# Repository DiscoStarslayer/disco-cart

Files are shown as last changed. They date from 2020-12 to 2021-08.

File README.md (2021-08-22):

# V.Smile Disco-Cart
Custom developer cartridge that easily enables the following
- Ability to dump retail cartridges over Serial or to an SD card
- Ability to flash roms over serial or an SD card to built in flash memory
- Booting cartridge on real V.Smile hardware
- Use Teensy to fuzz data + address bus while system is online (WIP)
- "Stealth" switch to disable sense pinout to allow console to boot as if Cartridge was not inserted

## Contents

- [Cartridge](#cartridge)
- [Usage](#usage)
- [Examples](#examples)
    + [Read retail cartridge to local file over serial](#read-retail-cartridge-to-local-file-over-serial)
    + [Dump retail cartridge to SD card](#dump-retail-cartridge-to-sd-card)
    + [Flash local rom to flashcart](#flash-local-rom-to-flashcart)
- [Args](#args)
    + [`port`](#-port-)
    + [`out`](#-out-)
    + [`limit`](#-limit-)
    + [`bank`](#-bank-)
    + [`mode`](#-mode-)
    + [`name`](#-name-)
    + [`length`](#-length-)
- [Contributing](#contributing)

## Cartridge

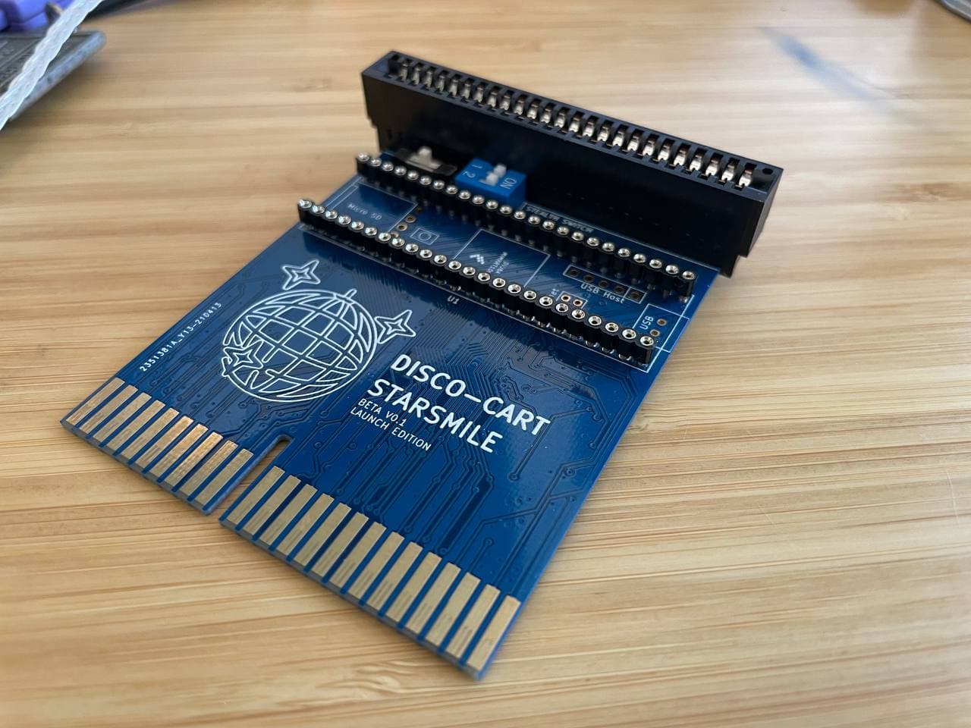
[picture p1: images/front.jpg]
Disco-Cart Front

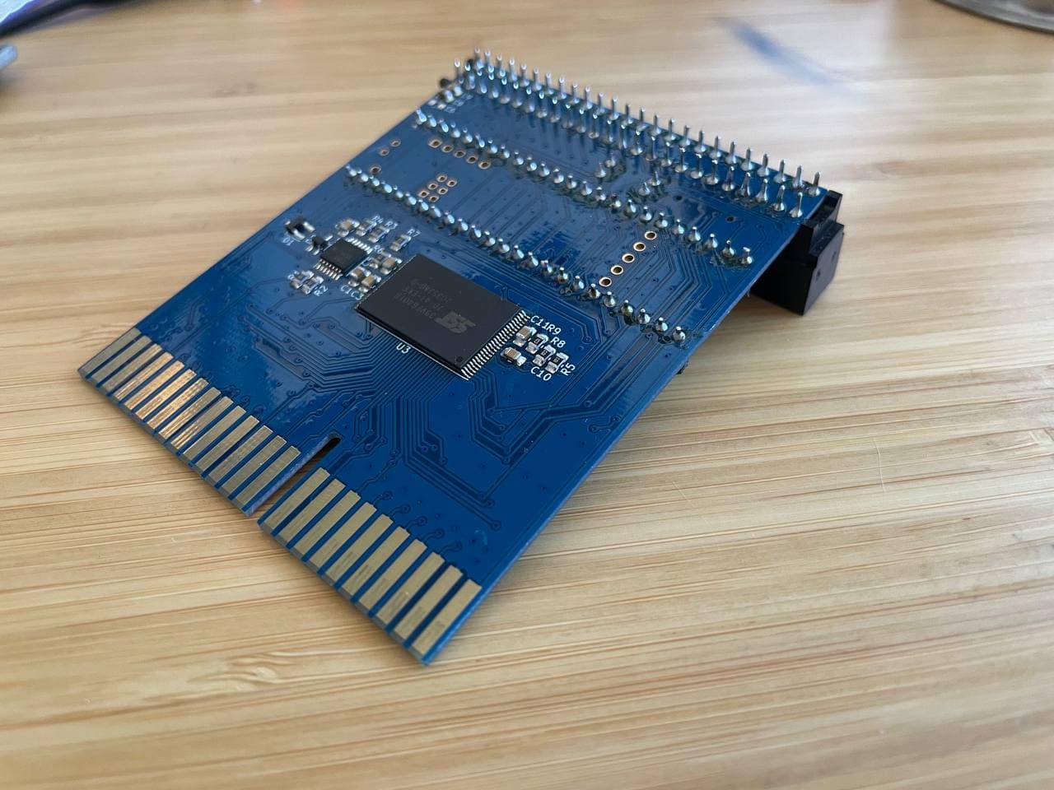
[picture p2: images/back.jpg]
Disco-Cart Back


## Usage

1. Install [PlatformIO](https://platformio.org/) onto your local system.
2. Install latest LTS for [NodeJS](https://nodejs.org/en/) onto your local system.
3. Install supporting packages for serial management script: 
```shell
cd ./manager
yarn
```
4. Use PlatformIO to pull in required packages, build, and then deploy firmware onto your Teensy (optionally, flash [`firmware.hex`](https://github.com/DiscoStarslayer/vsmile-dumper/releases/download/v0.1/firmware.hex))
5. Socket Teensy into Disco-Cart, ensure USB port on teensy lines up with the USB silkscreen on the board
6. Move mode select switch to the desired position
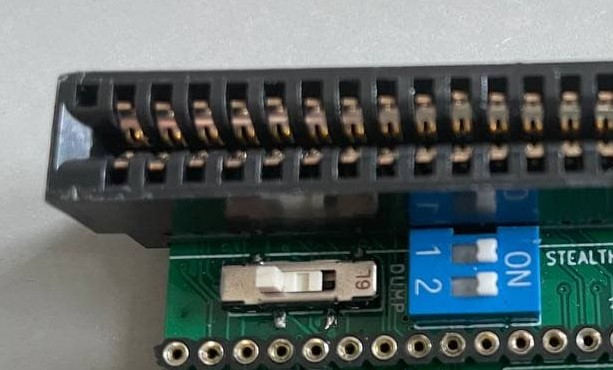
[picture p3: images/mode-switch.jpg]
Mode Select Switch

- `Left`: Cart mode, to insert into a V-Smile and boot a flashed rom
- `Middle`: Flash mode, select this mode to read/write to the internal flash on the Disco-Cart
- `Right`: Dump mode, select this mode to read/write from an inserted retail cartridge
7. Use manager scripts to perform your desired action

## Examples

### Read retail cartridge to local file over serial

```shell
# Switch: Dump mode
node .\index.js --port=COM3 --out=./thomas.bin --limit=3FFFFF --bank=LOW
```

### Dump retail cartridge to SD card

```shell
# Switch: Dump mode
node .\index.js --port=COM3 --mode=sddump --name=thomas.bin --length=3FFFFF
```

### Flash local rom to flashcart

```shell
# Switch: Write mode
node .\index.js --port=COM3 --mode=write --rom=./thomas.bin
```

### Inserting into a V.Smile
Ensure mode select switch is in Cart mode. Teensy can remain inserted in cartridge while in this mode. If you wish to write a new flash, you can do so while the cartridge is inserted by first switching mode to Write mode and running the write action from the manager

## Args

### `port`

Determines the serial port to connect to, defaults to `COM3` for Windows or `/dev/ttyACM0` for Linux.

### `out`

Relative file path to write the rom dump to, defaults to `./dump.bin`

### `limit`

Max address to dump to in hex. Banked cartridges generally have a 4MB and 2MB flash, so they need a limit of `1FFFFF` and `FFFFF` respectively. A single 8MB flash should accept `3FFFFF`.

### `bank`

If cartridge is banked, select which bank to dump. Defaults to `LOW`, non-banked cartridges should be set to `LOW`.

### `mode`

Which mode to operate the teensy in. Accepts `dump`, `write` and `sddump`.

### `name`

When writing to SD card, the file name to write to

### `length`

When writing to SD card, the size of the file to be written, in hex.

## Contributing

Project is fully open source under GPL3, including hardware design.
- `cartridge`: Hardware design as a KiCad Project
- `manager`: JS Script to aid with interfacing the Teensy over serial
- `src`: C++ Platform IO source for Teensy 4.1

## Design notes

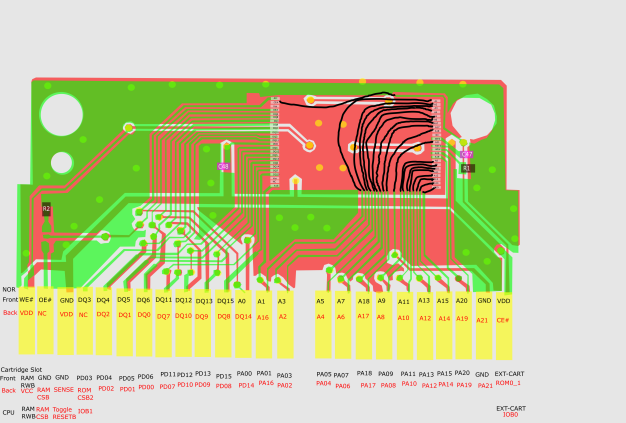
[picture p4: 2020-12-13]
docs/vsmile-pinout.png

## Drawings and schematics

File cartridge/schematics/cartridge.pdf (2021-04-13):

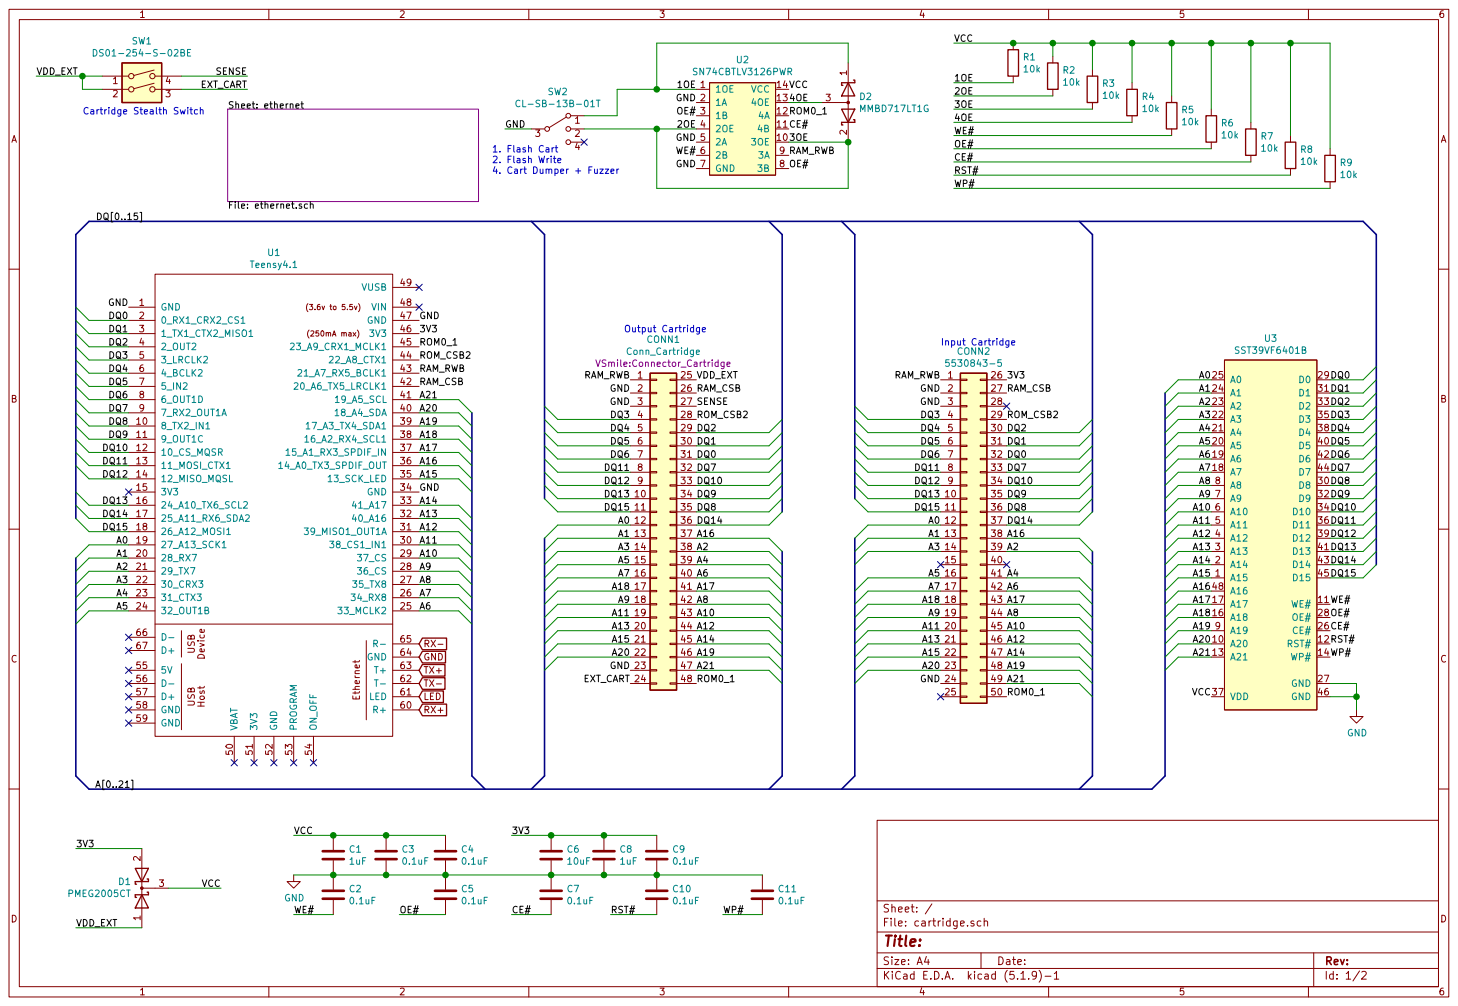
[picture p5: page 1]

WP# RST# CE# OE# WE# VCC

1. Flash Cart 2. Flash Write
4. Cart Dumper + Fuzzer

File: cartridge.sch Sheet: /
Id: 1/2 Title:

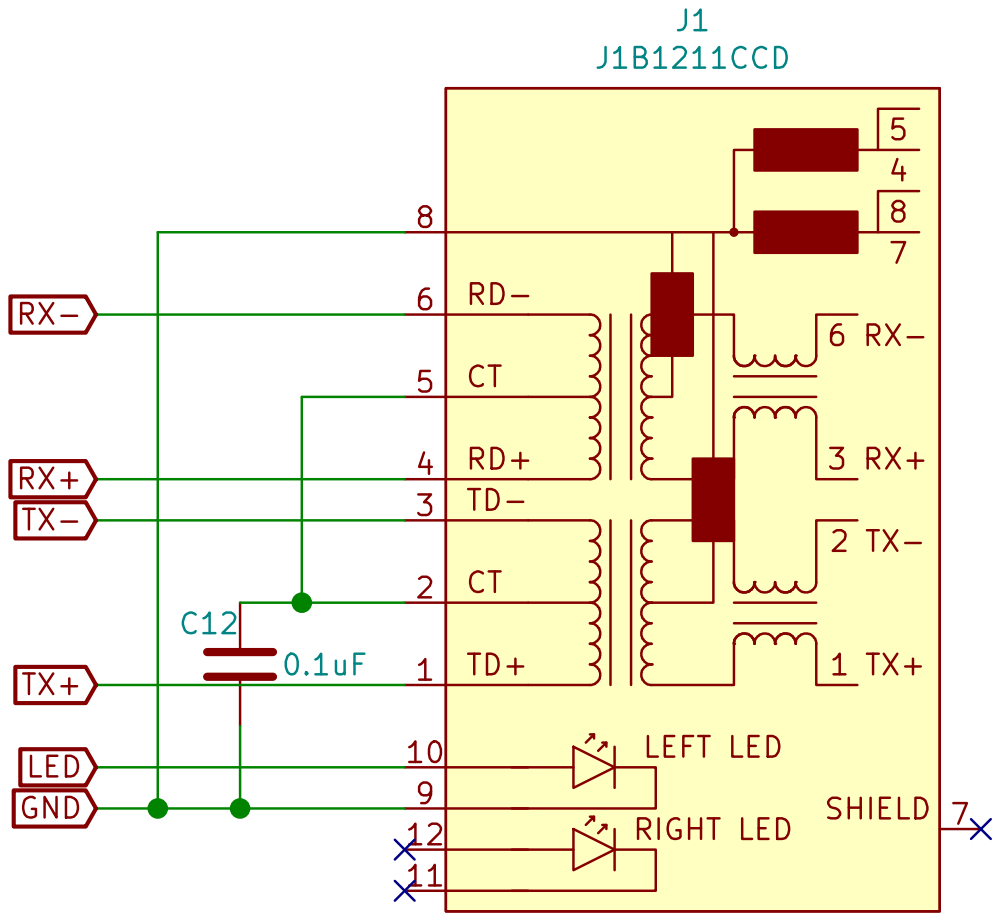
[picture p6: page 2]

0.1uF TX+ RX+ RX- LED GND

Id: 2/2 Title: File: ethernet.sch Sheet: /ethernet/

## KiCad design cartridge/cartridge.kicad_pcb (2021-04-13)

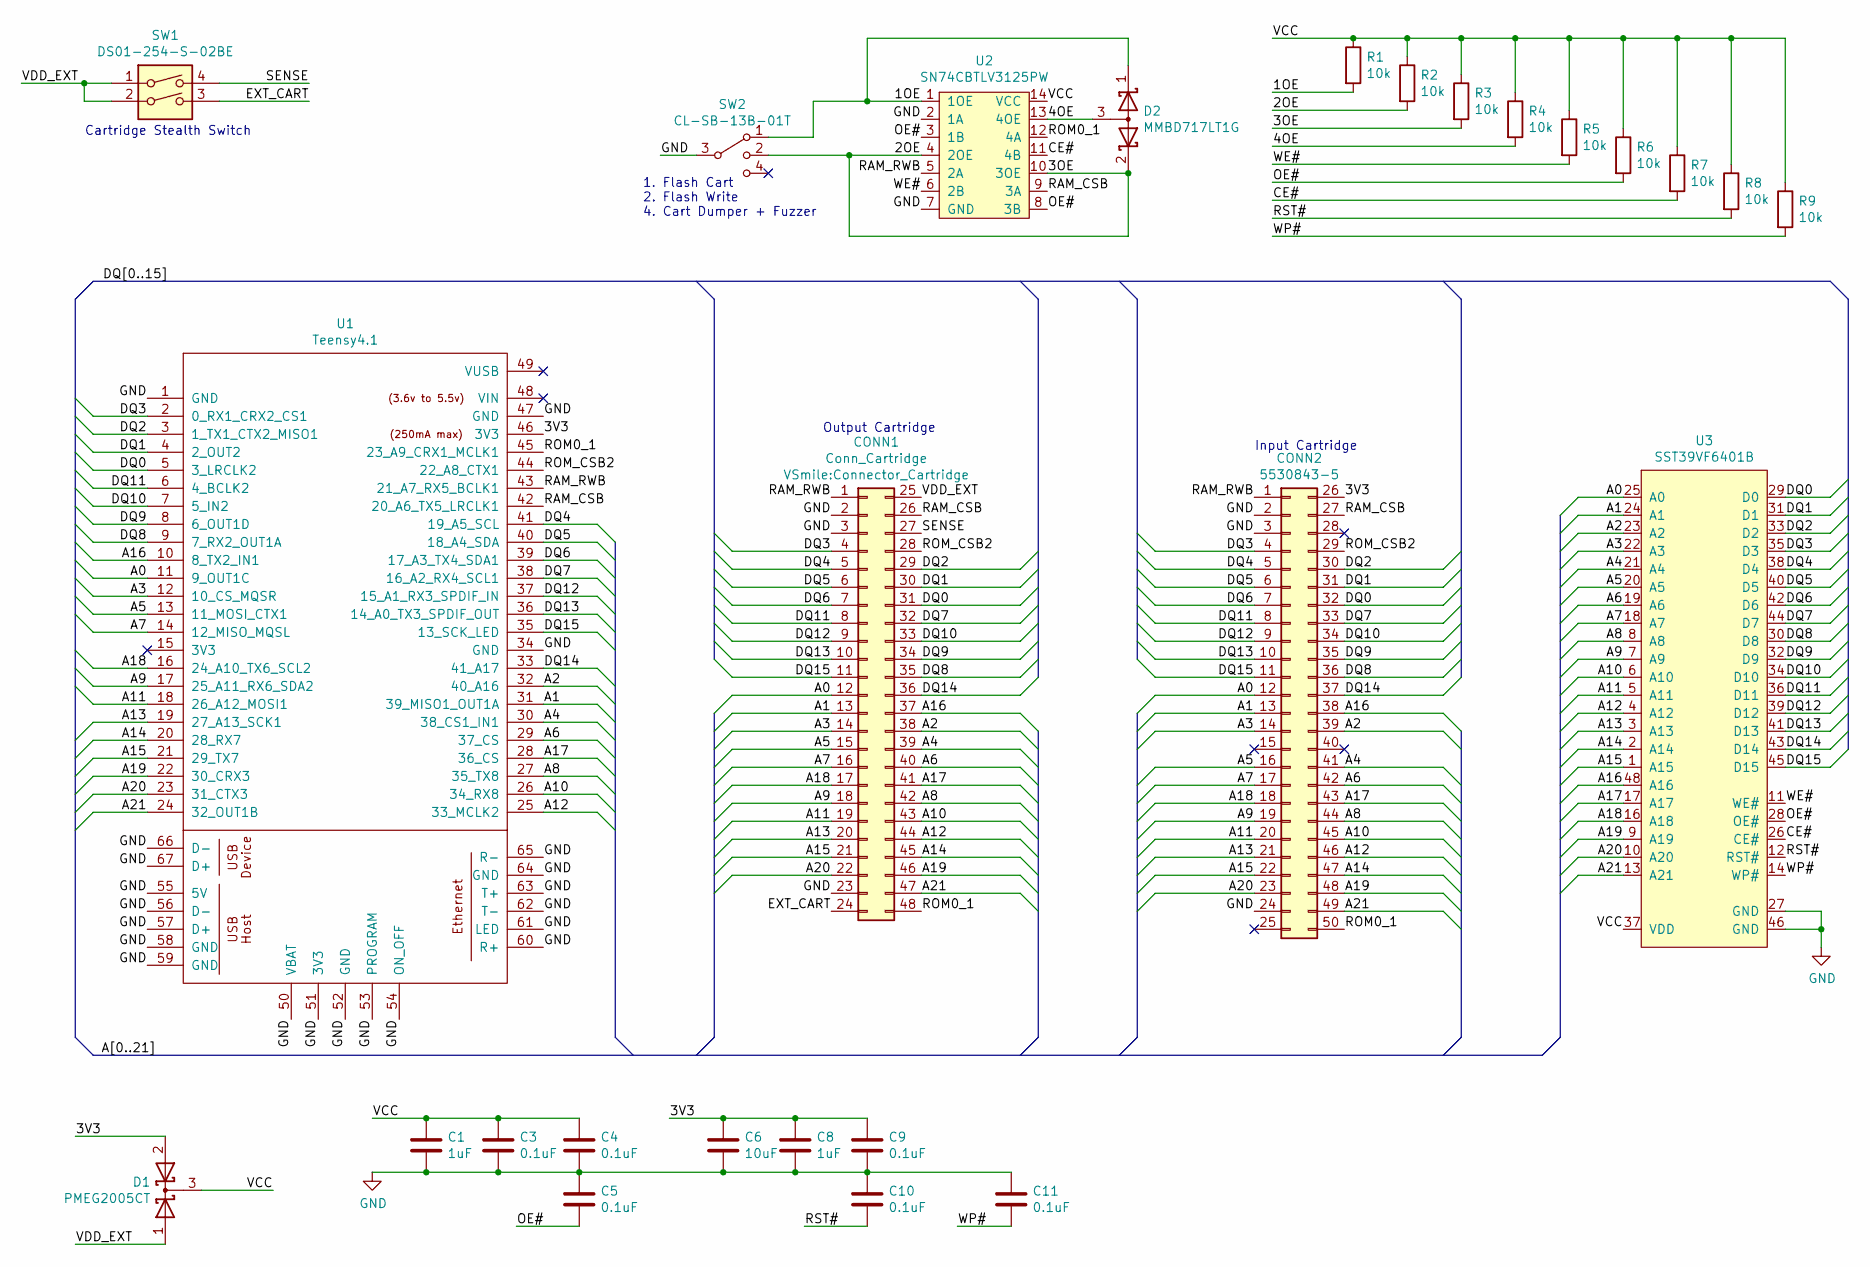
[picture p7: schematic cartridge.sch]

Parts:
C1, C8: 1uF; C_0805_2012Metric_Pad1.18x1.45mm_HandSolder
C3, C4, C5, C9, C10, C11: 0.1uF; C_0805_2012Metric_Pad1.18x1.45mm_HandSolder
C6: 10uF; C_0805_2012Metric_Pad1.18x1.45mm_HandSolder
CONN1: Conn_Cartridge; Connector_Cartridge
CONN2: 5530843-5
D1: PMEG2005CT; SOT-23_Handsoldering
D2: MMBD717LT1G‎; SOT-323_SC-70_Handsoldering
R1, R2, R3, R4, R5, R6, R7, R8, R9: 10k; R_0805_2012Metric_Pad1.20x1.40mm_HandSolder
SW1: DS01-254-S-02BE
SW2: CL-SB-13B-01T‎; CL-SB-13B-01T
U1: Teensy4.1; Teensy41
U2: SN74CBTLV3125PW; TSSOP-14_4.4x5mm_P0.65mm
U3: SST39VF6401B; TSOP-I-48_18.4x12mm_P0.5mm

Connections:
/1OE: D2.1 (K), R1.2, SW2.1, U2.1 (1OE)
/2OE: D2.2 (K), R2.2, R3.2, SW2.2, U2.4 (2OE), U2.10 (3OE)
/3V3: C6.1, C8.1, C9.1, CONN2.26, D1.2 (A), U1.46 (3V3)
/4OE: D2.3 (A), R4.2, U2.13 (4OE)
/A0: CONN1.12, CONN2.12, U1.11 (9_OUT1C), U3.25 (A0)
/A1: CONN1.13, CONN2.13, U1.31 (39_MISO1_OUT1A), U3.24 (A1)
/A2: CONN1.38, CONN2.39, U1.32 (40_A16), U3.23 (A2)
/A3: CONN1.14, CONN2.14, U1.12 (10_CS_MQSR), U3.22 (A3)
/A4: CONN1.39, CONN2.41, U1.30 (38_CS1_IN1), U3.21 (A4)
/A5: CONN1.15, CONN2.16, U1.13 (11_MOSI_CTX1), U3.20 (A5)
/A6: CONN1.40, CONN2.42, U1.29 (37_CS), U3.19 (A6)
/A7: CONN1.16, CONN2.17, U1.14 (12_MISO_MQSL), U3.18 (A7)
/A8: CONN1.42, CONN2.44, U1.27 (35_TX8), U3.8 (A8)
/A9: CONN1.18, CONN2.19, U1.17 (25_A11_RX6_SDA2), U3.7 (A9)
/A10: CONN1.43, CONN2.45, U1.26 (34_RX8), U3.6 (A10)
/A11: CONN1.19, CONN2.20, U1.18 (26_A12_MOSI1), U3.5 (A11)
/A12: CONN1.44, CONN2.46, U1.25 (33_MCLK2), U3.4 (A12)
/A13: CONN1.20, CONN2.21, U1.19 (27_A13_SCK1), U3.3 (A13)
/A14: CONN1.45, CONN2.47, U1.20 (28_RX7), U3.2 (A14)
/A15: CONN1.21, CONN2.22, U1.21 (29_TX7), U3.1 (A15)
/A16: CONN1.37, CONN2.38, U1.10 (8_TX2_IN1), U3.48 (A16)
/A17: CONN1.41, CONN2.43, U1.28 (36_CS), U3.17 (A17)
/A18: CONN1.17, CONN2.18, U1.16 (24_A10_TX6_SCL2), U3.16 (A18)
/A19: CONN1.46, CONN2.48, U1.22 (30_CRX3), U3.9 (A19)
/A20: CONN1.22, CONN2.23, U1.23 (31_CTX3), U3.10 (A20)
/A21: CONN1.47, CONN2.49, U1.24 (32_OUT1B), U3.13 (A21)
/CE#: R7.2, U2.11 (4B), U3.26 (CE#)
/DQ0: CONN1.31, CONN2.32, U1.5 (3_LRCLK2), U3.29 (D0)
/DQ1: CONN1.30, CONN2.31, U1.4 (2_OUT2), U3.31 (D1)
/DQ2: CONN1.29, CONN2.30, U1.3 (1_TX1_CTX2_MISO1), U3.33 (D2)
/DQ3: CONN1.4, CONN2.4, U1.2 (0_RX1_CRX2_CS1), U3.35 (D3)
/DQ4: CONN1.5, CONN2.5, U1.41 (19_A5_SCL), U3.38 (D4)
/DQ5: CONN1.6, CONN2.6, U1.40 (18_A4_SDA), U3.40 (D5)
/DQ6: CONN1.7, CONN2.7, U1.39 (17_A3_TX4_SDA1), U3.42 (D6)
/DQ7: CONN1.32, CONN2.33, U1.38 (16_A2_RX4_SCL1), U3.44 (D7)
/DQ8: CONN1.35, CONN2.36, U1.9 (7_RX2_OUT1A), U3.30 (D8)
/DQ9: CONN1.34, CONN2.35, U1.8 (6_OUT1D), U3.32 (D9)
/DQ10: CONN1.33, CONN2.34, U1.7 (5_IN2), U3.34 (D10)
/DQ11: CONN1.8, CONN2.8, U1.6 (4_BCLK2), U3.36 (D11)
/DQ12: CONN1.9, CONN2.9, U1.37 (15_A1_RX3_SPDIF_IN), U3.39 (D12)
/DQ13: CONN1.10, CONN2.10, U1.36 (14_A0_TX3_SPDIF_OUT), U3.41 (D13)
/DQ14: CONN1.36, CONN2.37, U1.33 (41_A17), U3.43 (D14)
/DQ15: CONN1.11, CONN2.11, U1.35 (13_SCK_LED), U3.45 (D15)
/EXT_CART: CONN1.24, SW1.3
/OE#: C5.2, R6.2, U2.3 (1B), U2.8 (3B), U3.28 (OE#)
/RAM_CSB: CONN1.26, CONN2.27, U1.42 (20_A6_TX5_LRCLK1), U2.9 (3A)
/RAM_RWB: CONN1.1, CONN2.1, U1.43 (21_A7_RX5_BCLK1), U2.5 (2A)
/ROM0_1: CONN1.48, CONN2.50, U1.45 (23_A9_CRX1_MCLK1), U2.12 (4A)
/ROM_CSB2: CONN1.28, CONN2.29, U1.44 (22_A8_CTX1)
/RST#: C10.2, R8.2, U3.12 (RST#)
/SENSE: CONN1.27, SW1.4
/VCC: C1.1, C3.1, C4.1, D1.3 (K), R1.1, R2.1, R3.1, R4.1, R5.1, R6.1, R7.1, R8.1, R9.1, U2.14 (VCC), U3.37 (VDD)
/VDD_EXT: CONN1.25, D1.1 (A), SW1.1, SW1.2
/WE#: R5.2, U2.6 (2B), U3.11 (WE#)
/WP#: C11.2, R9.2, U3.14 (WP#)
GND: C1.2, C3.2, C4.2, C5.1, C6.2, C8.2, C9.2, C10.1, C11.1, CONN1.2, CONN1.3, CONN1.23, CONN2.2, CONN2.3, CONN2.24, SW2.3, U1.1 (GND), U1.34 (GND), U1.47 (GND), U1.50 (VBAT), U1.51 (3V3), U1.52 (GND), U1.53 (PROGRAM), U1.54 (ON_OFF), U1.55 (5V), U1.56 (D-), U1.57 (D+), U1.58 (GND), U1.59 (GND), U1.60 (R+), U1.61 (LED), U1.62 (T-), U1.63 (T+), U1.64 (GND), U1.65 (R-), U1.66 (D-), U1.67 (D+), U2.2 (1A), U2.7 (GND), U3.27 (GND), U3.46 (GND)

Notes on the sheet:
Output Cartridge
Cartridge Stealth Switch
Input Cartridge
1. Flash Cart 2. Flash Write 4. Cart Dumper + Fuzzer

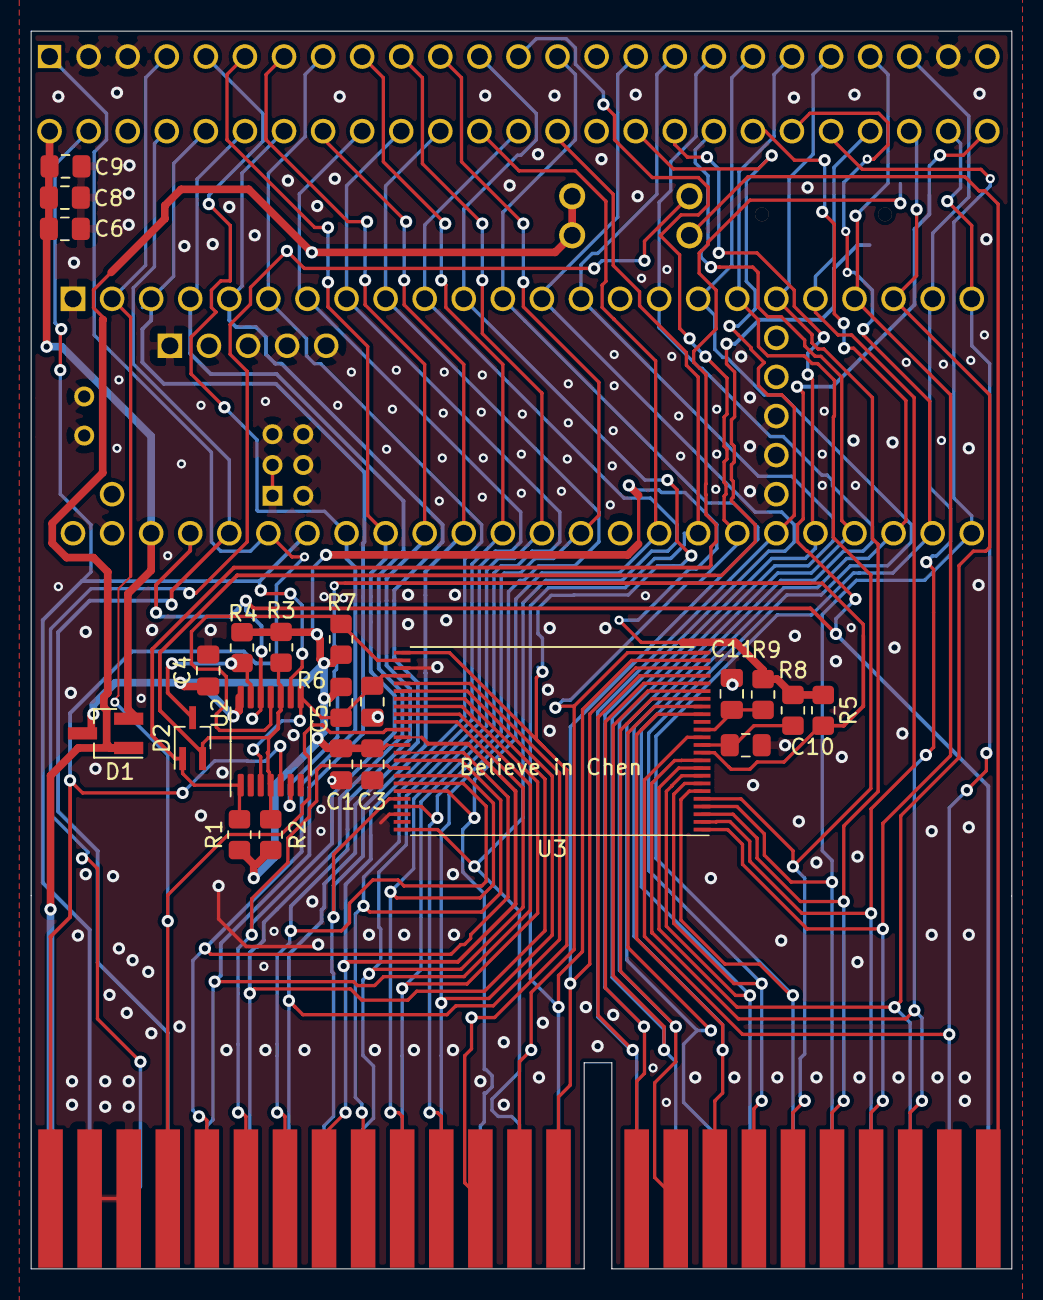
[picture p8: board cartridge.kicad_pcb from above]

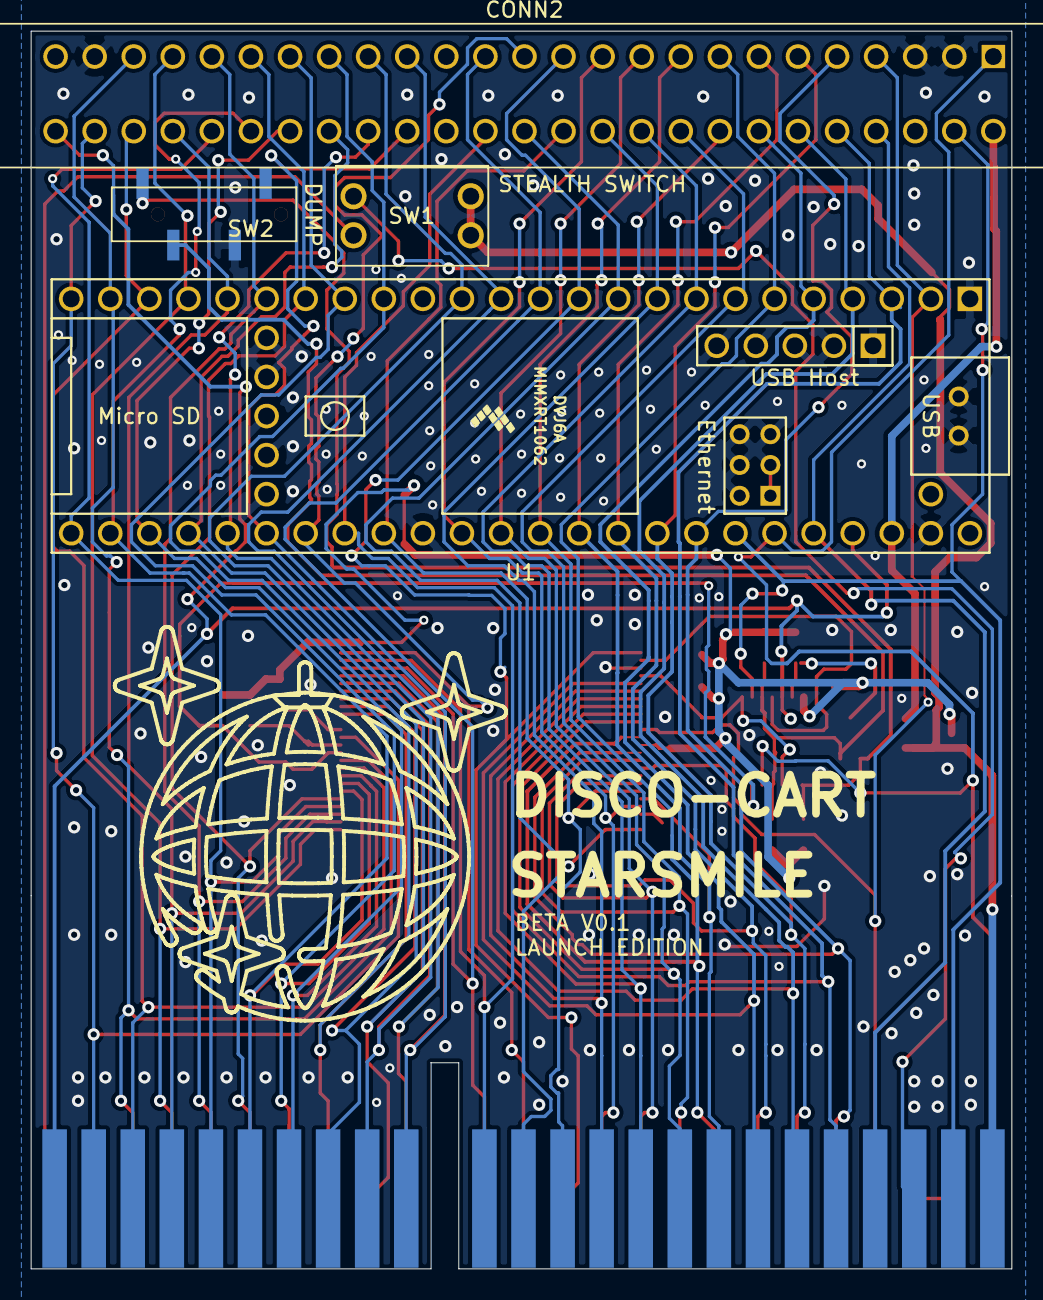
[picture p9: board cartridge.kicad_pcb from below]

Board: 2 copper layers, 63.7 x 80.5 mm, 28 parts (4 on the bottom side), 56 nets.

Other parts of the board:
DISCO-CART: logo

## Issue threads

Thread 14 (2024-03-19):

cl-sb-13b-01t alternative

vartem86, 2024-03-19:
I can’t find cl-sb-13b-01t on aliexpress, but they sell CL-SB-23B-01 there
Is it possible to use CL-SB-23B-01 instead of cl-sb-13b-01t by removing extra pins?

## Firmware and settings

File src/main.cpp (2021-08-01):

#include <Arduino.h>
#include "SdFat.h"
#include "main.h"
#include "RingBuf.h"

#define SPI_CLOCK SD_SCK_MHZ(50)

const size_t RING_BUF_SIZE = 400*512;

// v-smile has 22 bits for addressing
const uint8_t address [ADDRESS_BITS] = {
  9, // A0
  39,
  40,
  10,
  38,
  11, // A5
  37,
  12,
  35,
  25,
  34, // A10
  26,
  33,
  27,
  28,
  29, // A15
  8,
  36,
  24,
  30,
  31,
  32 // A21
};

// v-smile uses 16 bit wide data bus
const uint8_t data [DATA_BITS] = {
  3, // DQ0
  2,
  1,
  0,
  19,
  18, // DQ5
  17,
  16,
  7,
  6,
  5, // DQ10
  4,
  15,
  14,
  41,
  13 // DQ15
};

const int chipEnable = 23;
const int chipSelect = 22;
const int writeEnable = 21;
const int outputEnable = 20;

SdFs sd;
FsFile file;
bool sdDetected = false;

RingBuf<FsFile, RING_BUF_SIZE> ringBuf;

void setup() {
  // initialize address bus
  for (int i = 0; i < ADDRESS_BITS; i++) {
    pinMode(address[i], OUTPUT);

    // init low
    digitalWrite(address[i], LOW);
  }

  // initialize data bus
  for (int i = 0; i < DATA_BITS; i++) {
    pinMode(data[i], INPUT_PULLDOWN);
  }

  // initialize control bits
  pinMode(chipEnable, OUTPUT);
  digitalWrite(chipEnable, LOW);

  pinMode(chipSelect, OUTPUT);
  digitalWrite(chipSelect, LOW);

  pinMode(writeEnable, OUTPUT);
  digitalWrite(writeEnable, HIGH);

  pinMode(outputEnable, OUTPUT);
  digitalWrite(outputEnable, LOW);

  // initialize serial interface
  Serial.begin(4608000);
  delay(2);
  Serial.println("Started Serial COM");

  if (!sd.begin(SdioConfig(FIFO_SDIO))) {
    Serial.println("Failed to detect sd card");
    sd.initErrorHalt(&Serial);
  } else {
    sdDetected = true;
  }
}

void setupWrite() {
  // initialize address bus
  for (int i = 0; i < ADDRESS_BITS; i++) {
    pinMode(address[i], OUTPUT);

    // init low
    digitalWrite(address[i], LOW);
  }

  // initialize data bus
  for (int i = 0; i < DATA_BITS; i++) {
    pinMode(data[i], OUTPUT);
    digitalWrite(data[i], LOW);
  }

  // initialize control bits
  pinMode(chipEnable, OUTPUT);
  digitalWrite(chipEnable, LOW);

  pinMode(chipSelect, OUTPUT);
  digitalWrite(chipSelect, LOW);

  pinMode(writeEnable, OUTPUT);
  digitalWrite(writeEnable, HIGH);

  pinMode(outputEnable, OUTPUT);
  digitalWrite(outputEnable, HIGH);
}


void setAddress(unsigned int addr) {
  for (int i = 0; i < ADDRESS_BITS; i++) {
    digitalWriteFast(address[i], bitRead(addr, i));
  }
}

void setData(uint16_t wrd) {
  for (int i = 0; i < DATA_BITS; i++) {
    digitalWriteFast(data[i], bitRead(wrd, i));
  }
}

word readWord() {
  word dataWord = 0;

  for (int i = 0; i < DATA_BITS; i++) {
    bitWrite(dataWord, i, digitalReadFast(data[i]));
  }

  return dataWord;
}

word readData(unsigned int addr, int bank) {
  word dataWord;

  digitalWriteFast(chipEnable, HIGH);
  digitalWriteFast(chipSelect, HIGH);

  setAddress(addr);

  // Enable correct chip depending on if high or low bank is being read
  // chip enable and chip select are inverted, low = on
  if (bank == LOW) {
    digitalWriteFast(chipEnable, LOW);
  } else {
    digitalWriteFast(chipSelect, LOW);
  }

  delayNanoseconds(70);

  dataWord = readWord();

  digitalWrite(chipEnable, HIGH);
  digitalWrite(chipSelect, HIGH);

  return dataWord;
}

void writeWord(uint32_t addr, uint16_t wrd) {
  digitalWriteFast(writeEnable, HIGH);
  digitalWriteFast(outputEnable, HIGH);
  digitalWriteFast(chipEnable, LOW);

  setAddress(addr);
  setData(wrd);

  delayNanoseconds(15);

  digitalWriteFast(writeEnable, LOW);

  delayNanoseconds(40);

  digitalWriteFast(writeEnable, HIGH);

  delayNanoseconds(15);
}

void writeData(uint32_t addr, uint16_t wrd) {
  writeWord(0x555, 0xAA);
  writeWord(0x2AA, 0x55);
  writeWord(0x555, 0xA0);
  writeWord(addr, wrd);

  delayMicroseconds(10);
}

void eraseData() {
  writeWord(0x555, 0xAA);
  writeWord(0x2AA, 0x55);
  writeWord(0x555, 0x80);
  writeWord(0x555, 0xAA);
  writeWord(0x2AA, 0x55);
  writeWord(0x555, 0x10);

  delayMicroseconds(50000);
}

// Tool to print an integer in a hexadecimal representation
void printHex(int num, int precision) {
  char tmp[16];
  char format[128];

  sprintf(format, "%%.%dX", precision);

  sprintf(tmp, format, num);
  Serial.print(tmp);
}

uint8_t hexDecimalToBin(char decimal) {
  switch(decimal) {
    case '0':
      return 0;
    case '1':
      return 1;
    case '2':
      return 2;
    case '3':
      return 3;
    case '4':
      return 4;
    case '5':
      return 5;
    case '6':
      return 6;
    case '7':
      return 7;
    case '8':
      return 8;
    case '9':
      return 9;
    case 'a':
      return 10;
    case 'b':
      return 11;
    case 'c':
      return 12;
    case 'd':
      return 13;
    case 'e':
      return 14;
    case 'f':
      return 15;
    default:
      return 0;
  }
}

COMMAND stringToCommand(const String &commandString, uint32_t &address, uint16_t &wrd, char fileName[]) {
  if (commandString == String("BLOW")) {
    return BANK_LOW;
  } else if (commandString == String("BHI")) {
    return BANK_HIGH;
  } else if (commandString == String("ACK")) {
    return ACK;
  } else if (commandString == String("ERS")) {
    return ERASE;
  } else if (commandString.startsWith(String('R'))) {
    String addressString = commandString.substring(1);

    address = 0;
    for (uint32_t i = 0; i < addressString.length(); i++) {
      uint8_t hexDecimal = hexDecimalToBin(addressString.charAt(i));

      uint8_t offset = (addressString.length() - 1 - i) * 4;

      address = address + ((hexDecimal & 0xF) << offset);
    }

    address = address & 0x3FFFFF;
    return READ;
  } else if (commandString.startsWith(String('W'))) {
    String addressString = commandString.substring(1);

    address = 0;
    uint32_t splitPoint = 0;
    uint8_t decimals[7] = {0, 0, 0, 0, 0, 0, 0};
    for (; addressString.charAt(splitPoint) != ':'; splitPoint++) {
      decimals[splitPoint] = hexDecimalToBin(addressString.charAt(splitPoint));
    }

    for (uint32_t j = 0; j < splitPoint; j++) {
      uint8_t offset = (splitPoint - 1 - j) * 4;

      address = address + ((decimals[j] & 0xF) << offset);
    }

    address = address & 0x3FFFFF;

    String wordString = commandString.substring(splitPoint + 1);

    wrd = 0;
    for (uint32_t i = 0; i < wordString.length(); i++) {
      uint8_t hexDecimal = hexDecimalToBin(wordString.charAt(i));

      uint8_t offset = (wordString.length() - 1 - i) * 4;

      wrd = wrd + ((hexDecimal & 0xF) << offset);
    }

    return WRITE;
  } else if (commandString.startsWith(String('D'))) {
    String dumpString = commandString.substring(1);

    uint32_t splitPoint = 0;
    for (; dumpString.charAt(splitPoint) != ':'; splitPoint++) {
      fileName[splitPoint] = dumpString.charAt(splitPoint);
    }

    fileName[splitPoint + 1] = {'\0'};

    String limitString = commandString.substring(splitPoint + 1);

    address = 0;
    for (uint32_t i = 0; i < limitString.length(); i++) {
      uint8_t hexDecimal = hexDecimalToBin(limitString.charAt(i));
      uint8_t offset = (limitString.length() - 1 - i) * 4;

      address = address + ((hexDecimal & 0xF) << offset);
    }

    address = address & 0x3FFFFFF;

    return DUMP;
  } else {
    return UNKNOWN;
  }
}

uint32_t bank = LOW;
MODE currentMode = MODE_READ;

void switchMode(MODE mode) {
 if (mode == MODE_WRITE) {
   if (currentMode != MODE_WRITE) {
     setupWrite();
     currentMode = MODE_WRITE;

     delayMicroseconds(10);
   }
 } else {
   if (currentMode != MODE_READ) {
     setup();
     currentMode = MODE_READ;

     delayMicroseconds(10);
   }
 }
}

typedef struct {
  uint16_t wrd;
  uint32_t freq;
} differences;

uint32_t retryCount = 35;
uint16_t result[35];
differences diffs[35];
uint32_t difCnt;
uint32_t largestFreq;

void readSerialCommand(String command) {
  uint32_t address = 0;
  uint16_t wrd = 0;
  size_t maxUsed = 0;
  char fileName[FILE_NAME_LIMIT] = "";

  switch(stringToCommand(command, address, wrd, fileName)) {
    case(BANK_LOW):
      bank = LOW;
      return;
    case(BANK_HIGH):
      bank = HIGH;
      return;
    case(ERASE):
      switchMode(MODE_WRITE);

      eraseData();

      Serial.print("ACK\n");
      return;
    case(READ):
      switchMode(MODE_READ);

      for (uint32_t i = 0; i < retryCount; i++) {
        delayMicroseconds(1);
        result[i] = readData(address, bank);
      }

      difCnt = 1;
      largestFreq = 0;
      diffs[0] = {result[0], 1};

      for (uint32_t i = 0; i < retryCount; i++) {
        bool matchFound = false;
        for (uint32_t j = 0; j < difCnt; j++) {
          if (diffs[j].wrd == result[i]) {
            if (diffs[j].wrd != 0x0000) {
              diffs[j] = {result[i], diffs[j].freq + 1};
            }
            matchFound = true;
            break;
          }
        }

        if (!matchFound) {
          diffs[difCnt] = {result[i], 1};
          difCnt++;
        }
      }

      for (uint32_t i = 0; i < difCnt; i++) {
        if (diffs[i].freq > largestFreq) {
          result[0] = diffs[i].wrd;
          largestFreq = diffs[i].freq;
        }
      }

      printHex(result[0], 4);
      Serial.print("\n");
      return;
    case(WRITE):
      switchMode(MODE_WRITE);

      writeData(address, wrd);

      Serial.print("ACK\n");
      return;
    case(DUMP):
      switchMode(MODE_READ);

      if (!sdDetected) {
        Serial.println("No SD card!");
        return;
      }

      Serial.print("Writing file to ");
      Serial.print(fileName);
      Serial.print('\n');

      if (!file.open(fileName, O_RDWR | O_CREAT | O_TRUNC)) {
        Serial.println("Failed to open file!");
        return;
      }

      if (!file.preAllocate(address * 2)) {
        Serial.println("Failed to preallocate!");
        file.close();
        return;
      }

      ringBuf.begin(&file);

      for (uint32_t i = 0; i < address; i++) {
        if (i % 0xFFFF == 0) {
          Serial.print("Dumping... ");
          Serial.print((i * 100) / address);
          Serial.print("%\n");
        }

        size_t n = ringBuf.bytesUsed();

        if (n > maxUsed) {
          maxUsed = n;
        }

        if (n >= 512 && !file.isBusy()) {
          ringBuf.writeOut(512);
        }

        uint16_t data = readData(i, bank);

        ringBuf.write(&data, 2);
      }

      ringBuf.sync();
      file.truncate();
      file.close();

      Serial.print("Done! Max bytes used: ");
      Serial.print(maxUsed);
      Serial.print('\n');

      setup();
      return;
    case(ACK):
    default:
      Serial.println("Unused");
      return;
  }
}

void loop() {
  // Loop, waiting for serial commands
  if (Serial.available()) {
    readSerialCommand(Serial.readStringUntil('%'));
  }
}

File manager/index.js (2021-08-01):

const fs = require('fs');
const SerialPort = require('serialport');
const yargs = require('yargs/yargs');
const { hideBin } = require('yargs/helpers');

const { argv } = yargs(hideBin(process.argv))

const portPath = argv.port || (process.platform == 'win32' ? 'COM3' : '/dev/ttyACM0');

const port = new SerialPort(portPath, { baudRate: 4608000 });

const dumpBuffer = [];

const out = argv.out || './dump.bin';

const readCommandFromIndex = (index) => {
    return `R${index.toString(16)}%`
}

const read = index => {
    port.write(readCommandFromIndex(index));
}

const writeCommandFromIndex = (index, write) => {
    const str = `W${index.toString(16)}:${write.toString(16)}%`
    return str;
}

const write = (index, write) => {
    port.write(writeCommandFromIndex(index, write));
}

const erase = () => {
    port.write('ERS%');
}

let limit = argv.limit ? parseInt(argv.limit, 16) : 0x1F_FFFF;

const start = Date.now();
let timeElapsed = 0;

port.on('data', data => {
    if (argv.mode === 'dump') {
        const number = data.toString('ASCII');
        const bin = Buffer.alloc(2);
        bin.writeUInt16LE(parseInt(number, 16));
        dumpBuffer.push(bin);

        if (index % 0x00_FFF === 0) {
            timeElapsed = Date.now() - start;
            const percentCompleted = index / limit;

            const estTimeRemaining = Math.round((timeElapsed / percentCompleted) * (1 - percentCompleted));
            console.log('Dumping...', `${Math.round(index / limit * 100)}%,`, Math.round(estTimeRemaining / 1000 / 60), "minutes left");
        }

        if (index === limit) {
            const completeBuffer = Buffer.concat(dumpBuffer);

            fs.writeFileSync(out, completeBuffer);
            console.log('Done');
            process.exit(0);
        } else {
            index += 1;
            read(index);
        }
    } else if (argv.mode === 'write') {
        if (!erased) {
            console.log('Done');
            erased = true;
        }

        if (index % 0x00_FFFF === 0) {
            console.log('Writing...', `${Math.round((index / (rom.length / 2) * 100))}%`)
        }

        if (index === rom.length / 2) {
            console.log('Done');
            process.exit(0);
        } else {
            write(index, rom.readUInt16LE(index * 2));
            index++;
        }
    } else if (argv.mode === 'sddump') {
        const result = data.toString('ASCII');
        console.log(result);

        if (result.includes('Done!')) {
            process.exit(0);
        }
    }
})

// Set bank
if (argv.bank === 'HIGH') {
    port.write('BHI%');
} else {
    port.write('BLOW%');
}

let index = 0x00_0000
let erased = false;
let rom;

if (argv.mode === 'dump') {
    // Read first word
    read(index);
} else if (argv.mode === 'write') {
    rom = fs.readFileSync(argv.rom);

    console.log('Erasing...');
    erase();
} else if (argv.mode === 'sddump') {
    console.log(`Dumping file ${argv.name}:${argv.length}`);
    port.write(`D${argv.name}:${argv.length}`);
}

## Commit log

2021-04-13 WIP Cartridge Dumping PCB (#4)
    Accurate dumping of existing V-Smile Cartridges
    Dumps let us test accuracy of flash cart
    Allow easy dumping of cartridges for end users for backup + preservation (already found an undumped/unknown release)
    Direct Teensy -> VSmile bus connection
    Allows fuzzing of address bus and listening on the data bus. Potentially can be used to dump firmware from blob-top BIOS's
    "Stealth Mode" DIP Switch to allow insertion of cartridge without triggering console detection to aid with bus pirating
    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
    [cartridge-B_Cu.gbr, cartridge-B_Mask.gbr, cartridge-B_SilkS.gbr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]
2021-08-01 update code with SD card logic, port to new cart design and teensy 4.1 (#5)
2026-03-02 sd: Allow cart to work without SD card inserted (#12)
    No reason to make the SD card required, replace Error Halt with Error Print.
